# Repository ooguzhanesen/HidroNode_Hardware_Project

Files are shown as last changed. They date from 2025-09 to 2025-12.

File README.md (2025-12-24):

# STM32WL HidroNode – Donanım Tasarım Dokümantasyonu

> **Hazırlayan:** Oğuzhan ESEN  
> **Proje Adı:** HidroNode Board 
> **Tarih:** 24 Eylül 2025  
> **Versiyon:** v1.0
---

## İçindekiler

1. [Giriş](#1-giriş)  
2. [Tasarımın Amacı ve Kapsamı](#2-tasarımın-amacı-ve-kapsamı)  
3. [Sistem Blok Diyagramı](#3-sistem-blok-diyagramı)  
4. [Tasarım Özeti](#4-tasarım-özeti)  
5. [Şematik ve PCB](#5-şematik-ve-pcb)  
6. [Test Notları](#6-test-notları)  
7. [Geliştirme ve İyileştirme Önerileri](#7-geliştirme-ve-iyileştirme-önerileri)
---

## 1. Giriş

Bu doküman, LoraSOM Kartının taşıyıcısını  olan HidroNode kartını açıklamayı amaçlamaktadır. 
Tasarım, aşağıdaki isterleri karşılamak üzere gerçekleştirilmiştir:

- LoraSOM kartı ile pin uyumu sağlanması.
- Sensörlerle Dijital haberleşme yapabilmesi için **(TPEC)** RS485 engtegresinin bulunması.
- Sensörlerle Analog haberleşme yapabilmesi için **(Radar)** 4-20mA okuma girişinin bulunması.
- Dijital çıkış ile çalışan sensörlerden veri okuyabilmesi için **(Yağmur Sensörü)** dijital girişin bulunması.
- Arazi koşullarında Akü ve benzeri bataryalarla çalışabilmesi için 7-28 V girişi regüle edebilesi.
- Sensör çıkışlarının votajının sabitlenmesi(15v).
- Tassaruf amacıyla sensorleri kullanılmadığında kapatması.
- Dijital giriş çıkışların izole edilmesi.

---

## 2. Tasarımın Amacı ve Kapsamı
Proje kapsamında, LoraSOM kartının güvenli şekilde sensörlerden gelen verileri okuması ve çevresel şartlarda çalışması amaçlanmaktadır.

Taşıyıcı kart, aşağıdaki teknik özellikleri ile ölçüm istasyonlarındaki ihtiyaçları karşılamaktadır:

- **RS485 Haberleşme**  
  MAX3075EESA entegresi ile TPEC gibi endüstriyel sensörler ile haberleşme sağlanır.

- **Analog Sensör Girişi (4–20 mA)**  
  150 Ω shunt direnç, 2 adet opamp ve zener koruma ile akım döngülü sensörlerden gelen analog değer 16 bit çözünürlüğe sahip ADS1115IDGS entegresine bağlanır. Bu entegre de I2C ile LoraSOM'a Bağlıdır.

- **Panel Gerilim Okuma**  
  150 kΩ ve 20 kΩ direnç bölücü ile güneş panelinden voltaj ölçümü yapılabilir.

- **İzole Dijital Giriş**  
  Optokuplör korumalı 2 adet dijital giriş ile dijital çıkışlı ( yağmur sensörü) sensörlerden veri okunabilir.

- **İzole Dijital Çıkışlar**  
  4 adet dijital çıkış LTV-847S entegresi sayesinde izole şekilde röle veya kontrol elemanları sürülebilir.

- **Geniş Giriş Gerilim Aralığı**  
  TPS54302 ve TPS62291DRVR entegreleri ile 7–28 V DC giriş, 5 V ve 3.3 V seviyelerine güvenli şekilde regüle edilir.

- **Sensör Güç çıkışlarının Sabitlenmesi ve Kontrolü (15V)**  
  MT3608 entegresi ile 5v 15v yükselterek sensörlerin akü voltajına bağımlı kalması engellenmiştir. Ayrıca MT3608 entegresin enable pini ile bu çıkışlar anahtarlanmaktadır. 

---

## 3. Sistem Blok Diyagramı

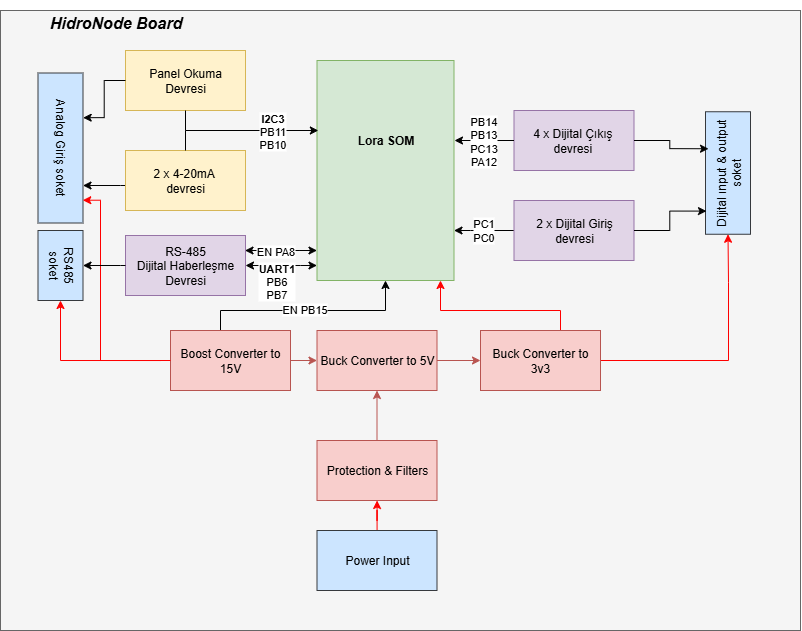
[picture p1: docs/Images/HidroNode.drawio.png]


## 4. Tasarım Özeti

Tasarım 4 katlı olacak şekikde KiCAD üzerinden tasarlanmıştır.

## 5. Şematik ve PCB
[Şematik için tıklayın](docs/HidroNode_Project.pdf)

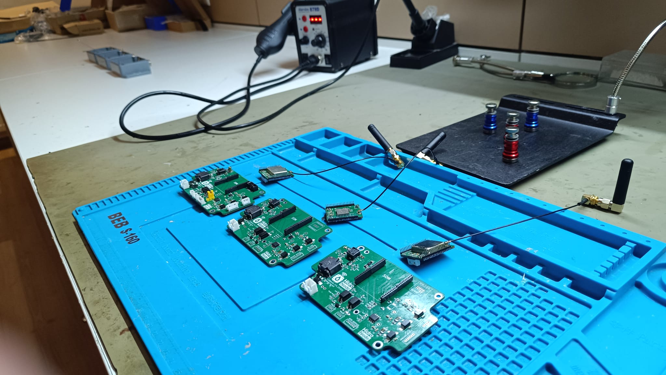
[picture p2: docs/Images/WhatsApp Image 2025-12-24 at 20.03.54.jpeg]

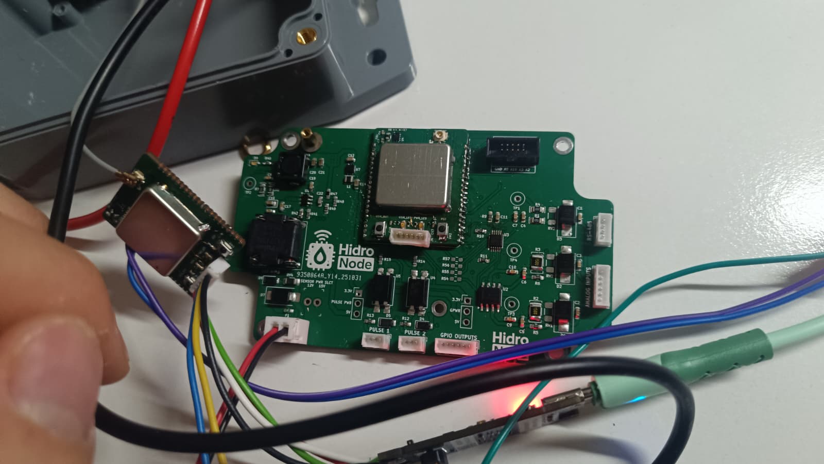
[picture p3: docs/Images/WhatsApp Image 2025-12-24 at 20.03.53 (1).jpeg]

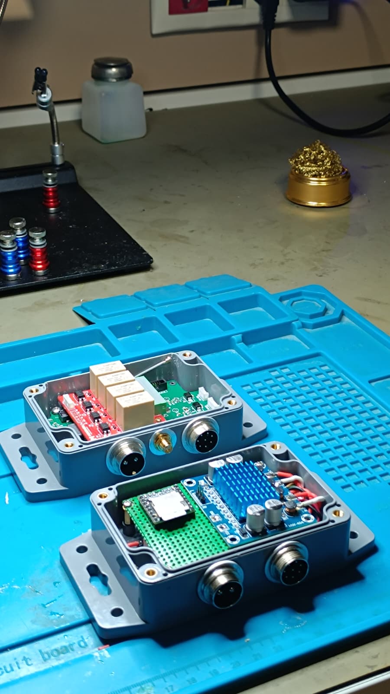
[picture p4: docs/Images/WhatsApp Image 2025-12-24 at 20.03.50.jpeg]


---
## 6. Test Notları
* 5v regülatör devresinde 75pf olmadıgı için en yakın deger olan 68pf kullanıldı.

---
## 7. Geliştirme ve İyileştirme Önerileri

* indüktör footprinti güncellenebilir.
* tvs diyot kıfı küçültülebilir.
* Genişleme portunun slikscreeni düzeltilecek. 
* Kart soket tipi degistirilebilir 

--- 

## Eksikler
* Anten kablosu alınacak.
* kart montajı için vida alınacak
* genişleme portu karsılık soketi alınacak
* hoparlor modulunun voltajı 3.3 volta dusurulecek.
* sbrr alınması gerek. 1 adet kaldı.  
* 150 ohm sont bitti.

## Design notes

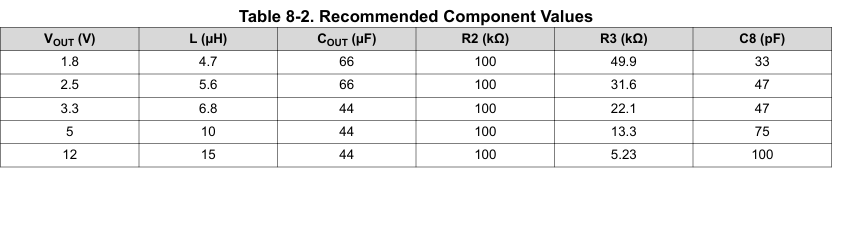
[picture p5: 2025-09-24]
docs/Images/Screenshot_4.png

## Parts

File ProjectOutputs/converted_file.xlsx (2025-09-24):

Reference | Value | Footprint | Qty | OZDISAN
C1,C2,C3,C5,C6,C7,C8,C9,C10 | 10nF | Capacitor_SMD:C_0603_1608Metric_Pad1.08x0.95mm_HandSolder | 9 | CL10B103KB8NNNC
C4,C11,C13,C15,C17,C19,C24 | 100nF | Capacitor_SMD:C_0603_1608Metric_Pad1.08x0.95mm_HandSolder | 7 | CC0603KRX7R9BB104
C12,C14,C16 | 10uF | Capacitor_SMD:C_0603_1608Metric,Capacitor_SMD:C_0603_1608Metric_Pad1.08x0.95mm_HandSolder,LED_SMD:LED_0805_2012Metric_Pad1.15x1.40mm_HandSolder | 3 | CL10A106KQ8NNNC,GRM21BC8YA106KE11L
C18,C20,C21,C23 | 22uF | Capacitor_SMD:C_0603_1608Metric_Pad1.08x0.95mm_HandSolder,Capacitor_SMD:C_1206_3216Metric_Pad1.33x1.80mm_HandSolder | 4 | CL31A226KAHNNNE,GRM188C61E226ME01J
C22 | 75pF | Capacitor_SMD:C_0603_1608Metric_Pad1.08x0.95mm_HandSolder | 1 | CL10C680JB8NNNC
D1,D2,D3,D7 | SMBJ28A-HT | Diode_SMD:D_SMB_Handsoldering | 4 | SMBJ28A-HT
D4,D5,D6,D8 | SBR3U40P1-7 | Diode_SMD:D_PowerDI-123 | 4 | SBR3U40P1-7
D9 | LED | LED_SMD:LED_0603_1608Metric_Pad1.05x0.95mm_HandSolder | 1 | HSMQ-C191
D10 | SS34 | digikey-footprints:DO-214AB | 1 | SS34-DO214AB-HT
F1 | 2A | Fuse:Fuse_0603_1608Metric_Pad1.05x0.95mm_HandSolder | 1 | 3412.0119.22
J1,J3,J4,J7,J8,J9,U1 | ~ | Connector_Hirose:Hirose_DF13-06P-1.25DSA_1x06_P1.25mm_Vertical,Connector_PinHeader_2.54mm:PinHeader_1x03_P2.54mm_Vertical,Connector_PinHeader_2.54mm:PinHeader_2x01_P2.54mm_Vertical,mergened_footprints:BoxHeader2x5_1.27,mergened_footprints:stm32wl_lora_som | 7 | 4573-06MTSB
J2 | B4B-PH-K-S_LF__SN_ | Connector_Hirose:Hirose_DF13-04P-1.25DSA_1x04_P1.25mm_Vertical | 1
J5,J6 | B3B-PH-K-S_LF__SN_ | Connector_Molex:Molex_PicoBlade_53047-0310_1x03_P1.25mm_Vertical | 2 | https://www.hepsiburada.com/labshop41-jst-1-25mm-3pin-20cm-kablolu-konnektor-beyaz-takim-x-1-adet-rf014-p-HBCV00006C588M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
J10 | 22-23-2021 | digikey-footprints:PinHeader_1x2_P2.54mm_Drill1.02mm | 1
L1 | 2.2uH | Inductor_SMD:L_Murata_DFE201610P | 1 | LQM2MPN2R2NG0L
L2 | PA2748NL | footprints:pa2748 | 1 | PA2748NL
L3 | 22uH | Inductor_SMD:L_12x12mm_H6mm | 1 | SRI1204-220M
L4 | 10uH | footprints:INDC6060X300 | 1 | SRI0704-100M
Q1,Q2,Q5,Q6,Q9 | BC817-40,215 | Package_TO_SOT_SMD:SOT-23 | 5 | BC817-40,215
Q3,Q4,Q7,Q8 | BC857B,215 | Package_TO_SOT_SMD:SOT-23-3 | 4 | BC857B,215
Q10 | BSN20 | Package_TO_SOT_SMD:SOT-23 | 1 | BSN20BK
R1,R7 | 150k | Resistor_SMD:R_0805_2012Metric_Pad1.20x1.40mm_HandSolder | 2 | TC0550B1503T5G
R2,R3,R26,R27,R38,R39 | 150 | Resistor_SMD:R_1206_3216Metric_Pad1.30x1.75mm_HandSolder,Resistor_SMD:R_1210_3225Metric | 6 | ERJ8GEYJ151V,RN73H2ETTD1500B25
R4,R8 | 20k | Resistor_SMD:R_0805_2012Metric_Pad1.20x1.40mm_HandSolder | 2 | TC0525B2002T5G
R5,R6,R17,R32,R33 | 1k | Resistor_SMD:R_0603_1608Metric_Pad0.98x0.95mm_HandSolder | 5 | CRT03F7E1001
R9,R10,R11,R14,R15,R22,R23,R24,R25,R34,R35,R36,R37,R44,R51,R52,R53 | 10k | Resistor_SMD:R_0603_1608Metric_Pad0.98x0.95mm_HandSolder | 17 | 0603SAJ0103TDE
R12,R13 | 1.1k | Resistor_SMD:R_0603_1608Metric_Pad0.98x0.95mm_HandSolder | 2 | 0603SAF1101T5E
R16,R20,R21,R28,R29,R43 | 1K | Resistor_SMD:R_0603_1608Metric_Pad0.98x0.95mm_HandSolder | 6 | CRT03F7E1001
R18,R19,R30,R31 | 680 | Resistor_SMD:R_0603_1608Metric_Pad0.98x0.95mm_HandSolder | 4 | 0603SAF6800T5E
R40,R50 | 210 | Resistor_SMD:R_0603_1608Metric_Pad0.98x0.95mm_HandSolder | 2 | 0603SAF2100T5E,RC0805FR-070RL
R41 | 511k | Resistor_SMD:R_0603_1608Metric_Pad0.98x0.95mm_HandSolder | 1 | 0603SAF1053T5E
R42 | 105k | Resistor_SMD:R_0603_1608Metric_Pad0.98x0.95mm_HandSolder | 1 | 0603SAF1053T5E
R45 | 75k | Resistor_SMD:R_0603_1608Metric_Pad0.98x0.95mm_HandSolder | 1 | 0603SAF7502T5E
R46 | 3.3k | Resistor_SMD:R_0603_1608Metric_Pad0.98x0.95mm_HandSolder | 1 | 0603SAJ0332T5E
R47 | 49.9 | Resistor_SMD:R_0603_1608Metric_Pad0.98x0.95mm_HandSolder | 1 | 0603SAF499JT5E
R48 | 100K | Resistor_SMD:R_0603_1608Metric_Pad0.98x0.95mm_HandSolder | 1 | RC0805JR-07100KL
R49 | 13.3K | Resistor_SMD:R_0603_1608Metric_Pad0.98x0.95mm_HandSolder | 1 | 0603SAF1332T5E
RV1,RV2,RV3,RV4 | TVM3B390K651TY | Resistor_SMD:R_1206_3216Metric_Pad1.30x1.75mm_HandSolder | 4 | TVM3B390K651TY
TP1,TP2,TP3,TP4 | TestPoint | TestPoint:TestPoint_Loop_D2.60mm_Drill0.9mm_Beaded | 4
U2 | OPA2197xD | Package_SO:SOIC-8_3.9x4.9mm_P1.27mm | 1 | OPA2197IDR
U3 | ADS1115IDGS | Package_SO:TSSOP-10_3x3mm_P0.5mm | 1 | ADS1115IDGST
U4,U5 | UPC817BG-C04-R | mergened_footprints:EL8171-S1-TU_EVE | 2 | UPC817BG-C04-R
U6 | LTV-847S | Package_DIP:SMDIP-16_W9.53mm | 1 | LTV-847S
U7 | TPS62291DRVR | footprints:WSON6 (2x2) | 1 | TPS62291DRVR
U8 | TPS54302 | Package_TO_SOT_SMD:SOT-23-6 | 1 | TPS54302DDCR
U9 | MT3608 | Package_TO_SOT_SMD:SOT-23-6 | 1 | https://www.direnc.net/mt3608-2a-max-dc-dc-step-up-power-module-arduino?language=tr&h=60f3a44c
U10 | Max3075EESA | Package_SO:SOIC-8_3.9x4.9mm_P1.27mm | 1

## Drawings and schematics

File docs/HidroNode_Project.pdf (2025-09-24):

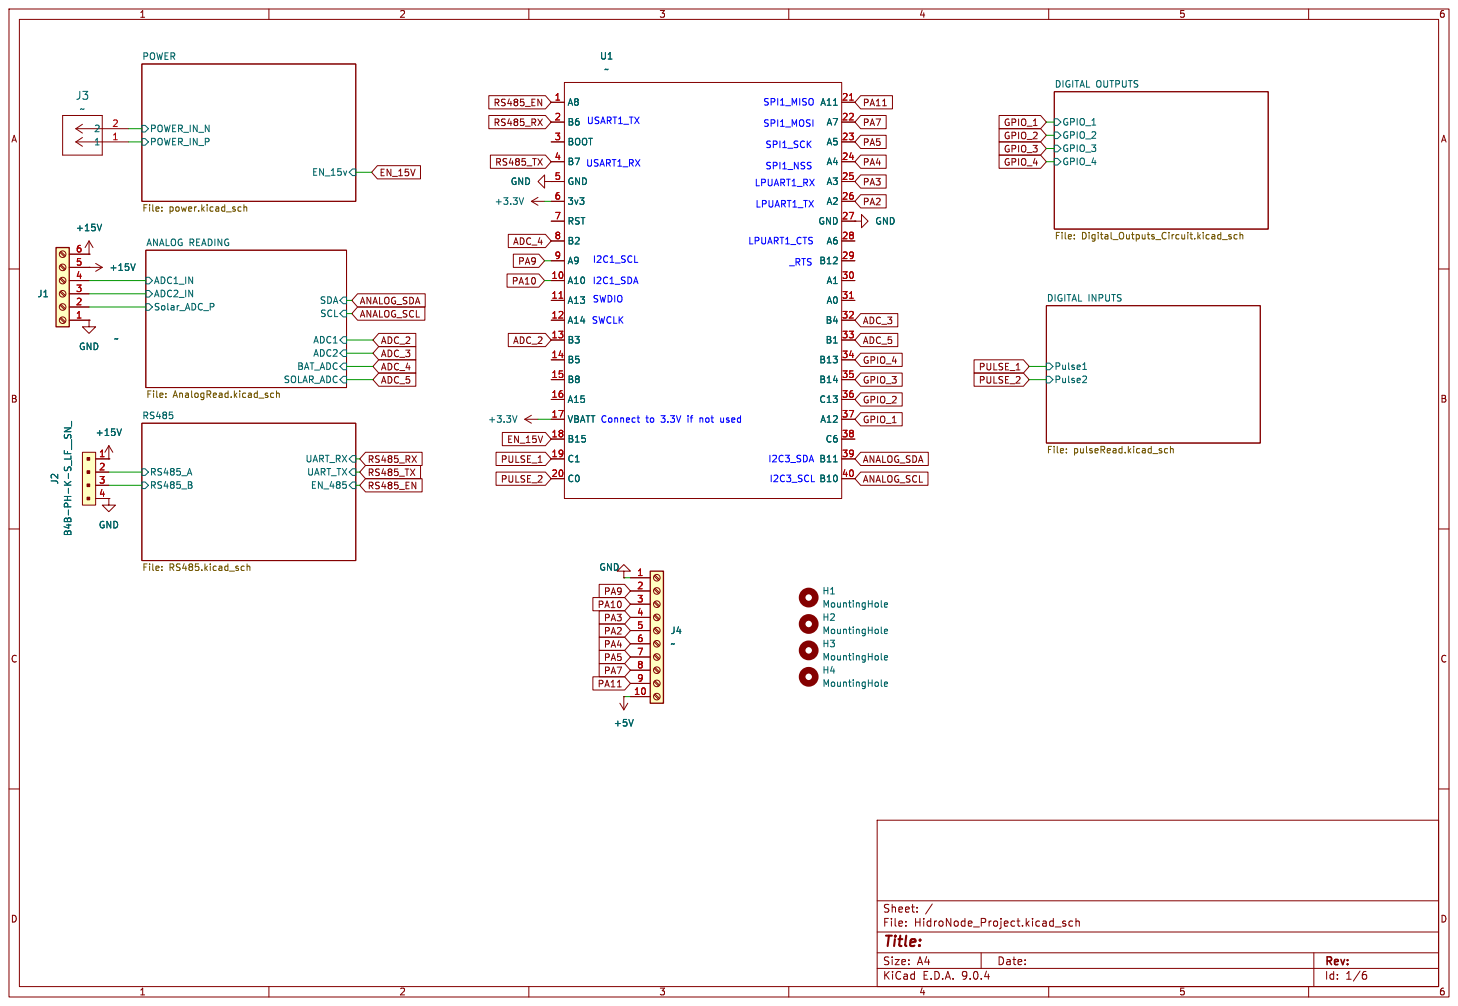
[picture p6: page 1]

SWCLK Connect to 3.3V if not used

Id: 1/6 Title: File: HidroNode_Project.kicad_sch Sheet: /

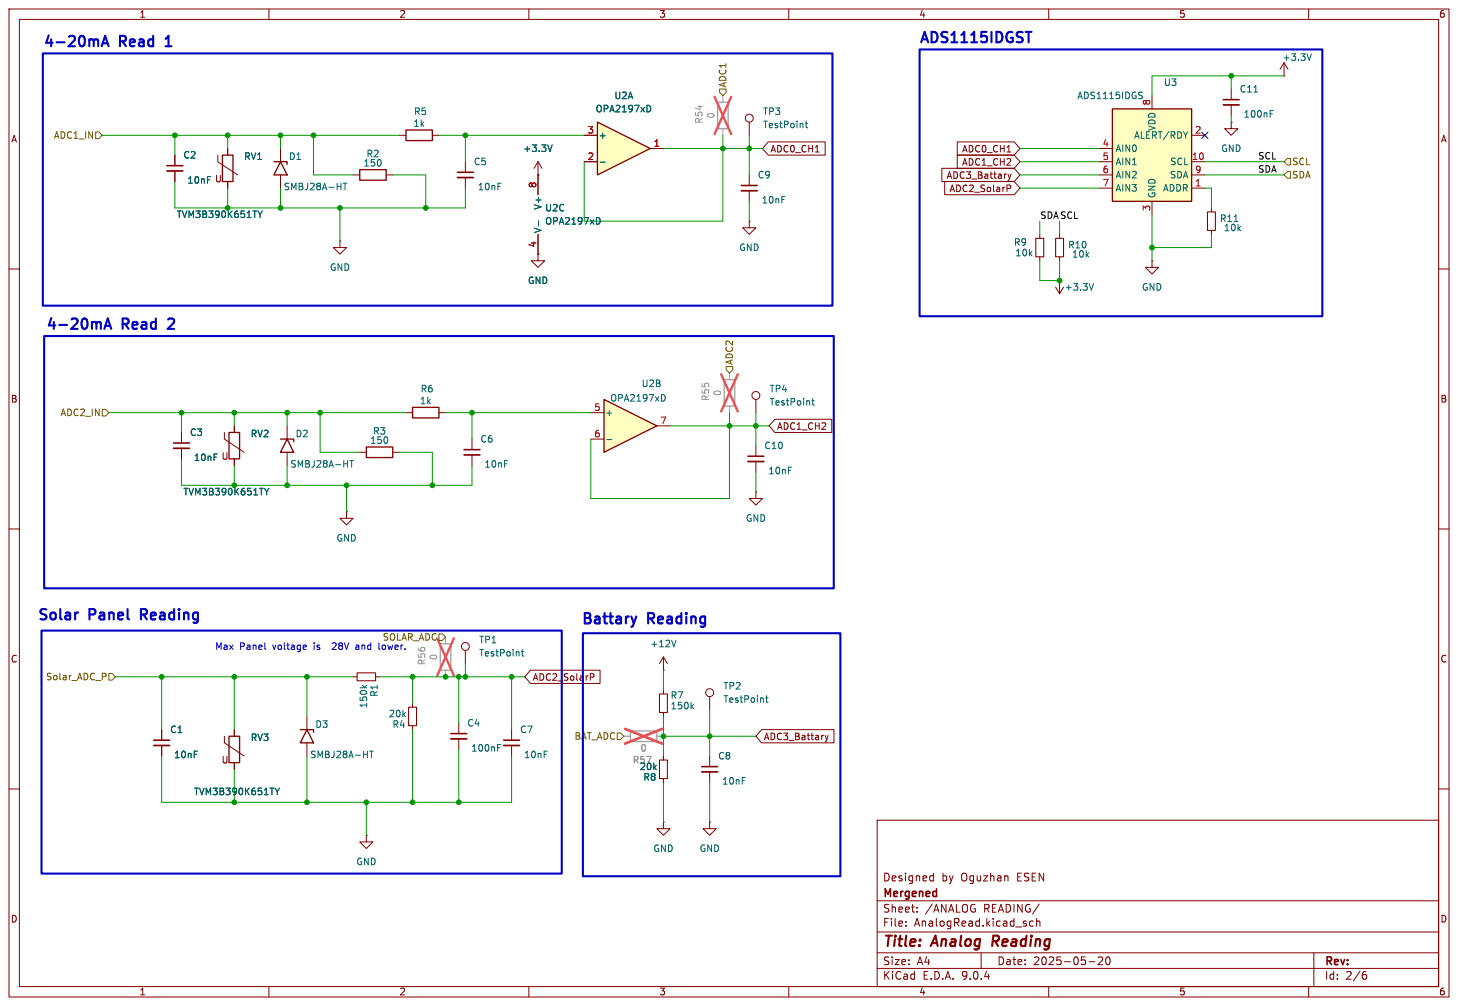
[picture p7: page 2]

3 ALERT/RDY 2 SCL 10 SDA 9 ADDR 1 U3 ADS1115IDGS GND

Id: 2/6 Title: Analog Reading

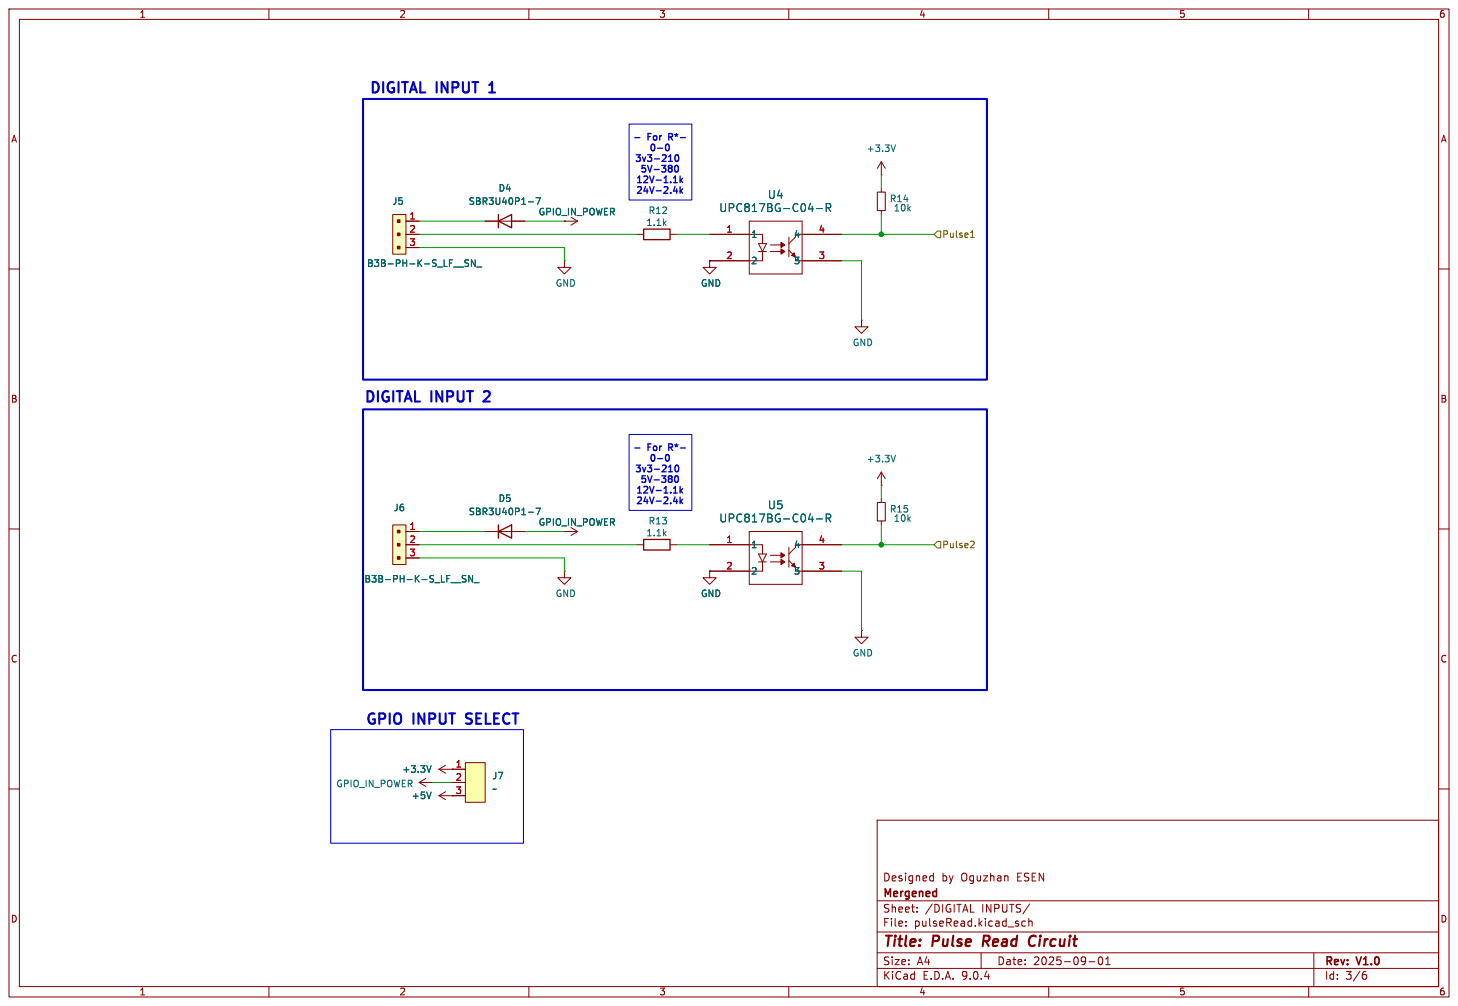
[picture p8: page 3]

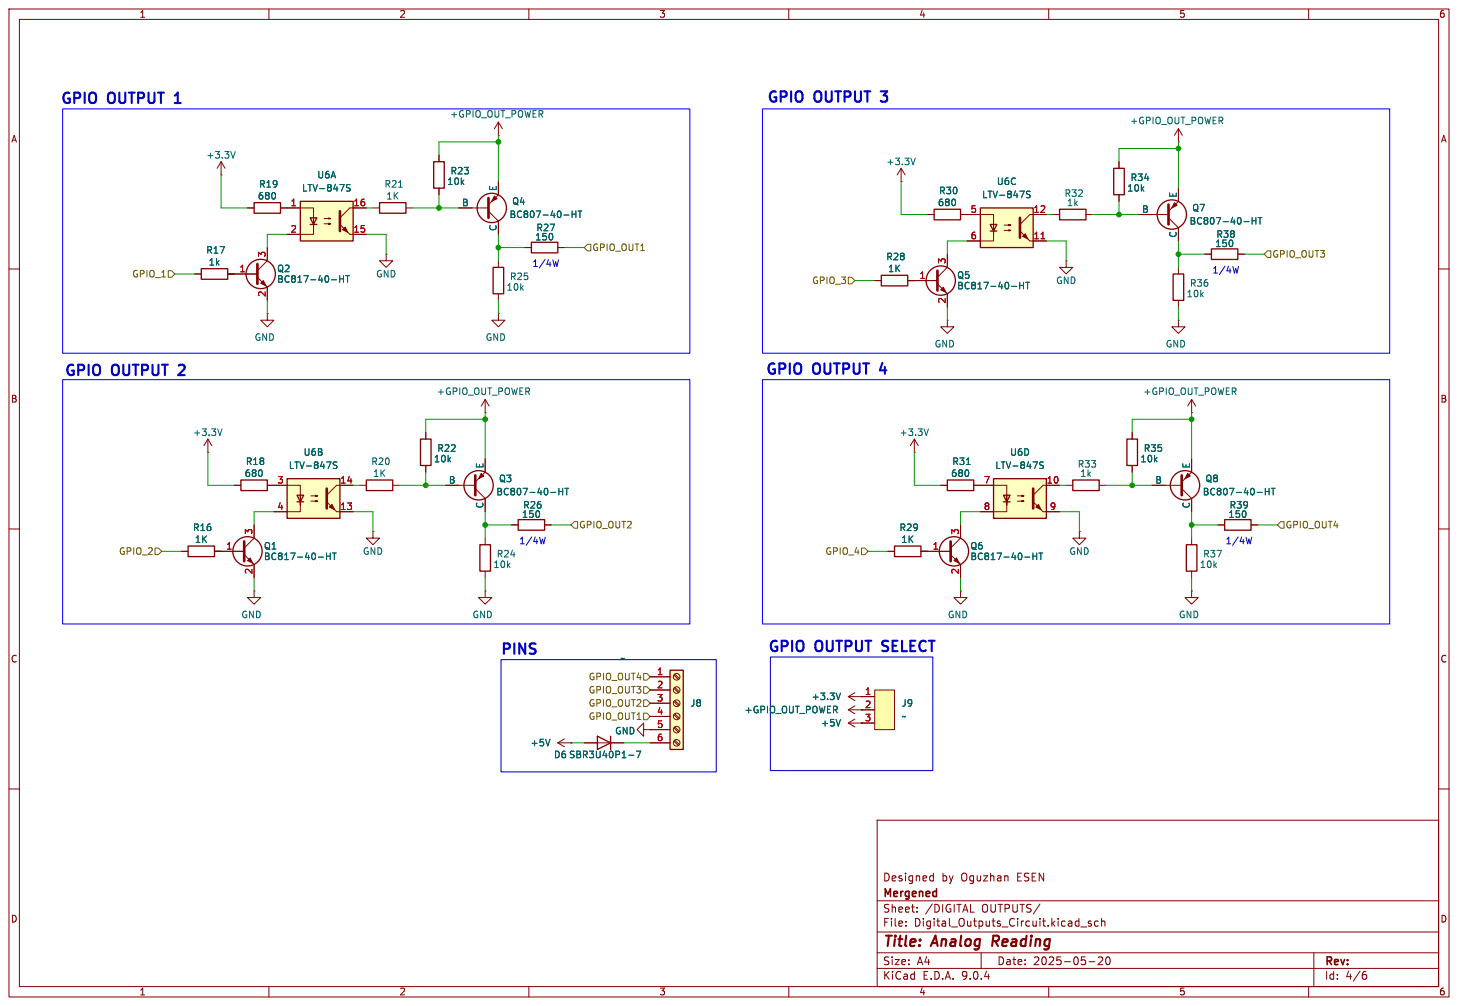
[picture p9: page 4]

Id: 4/6 Title: Analog Reading

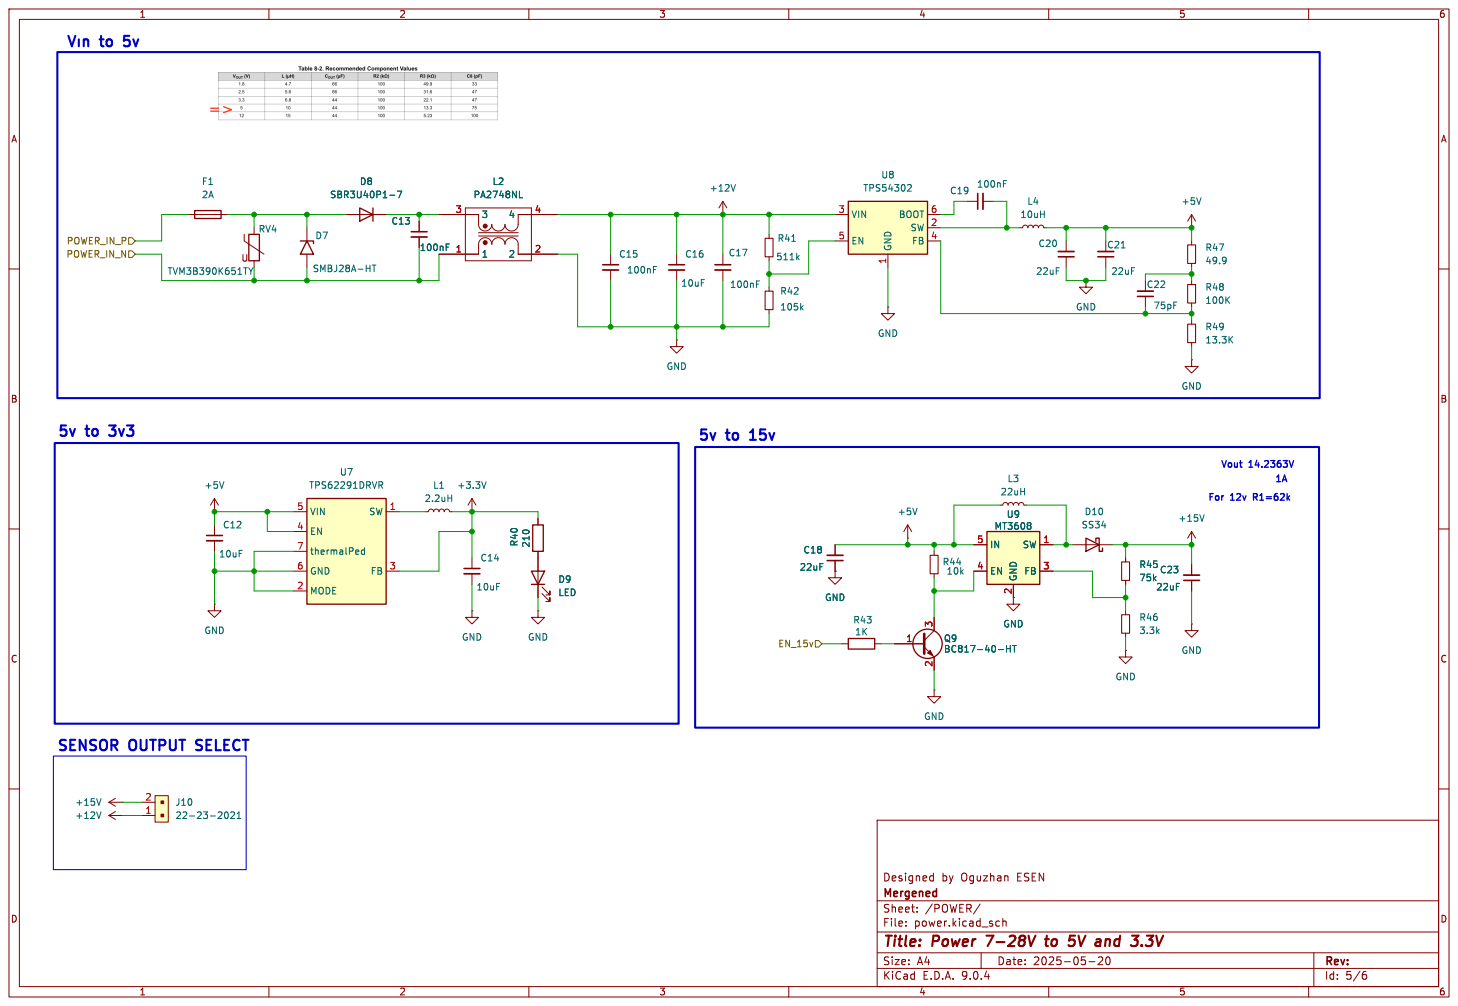
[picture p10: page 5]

File: power.kicad_sch Sheet: /POWER/ Mergened

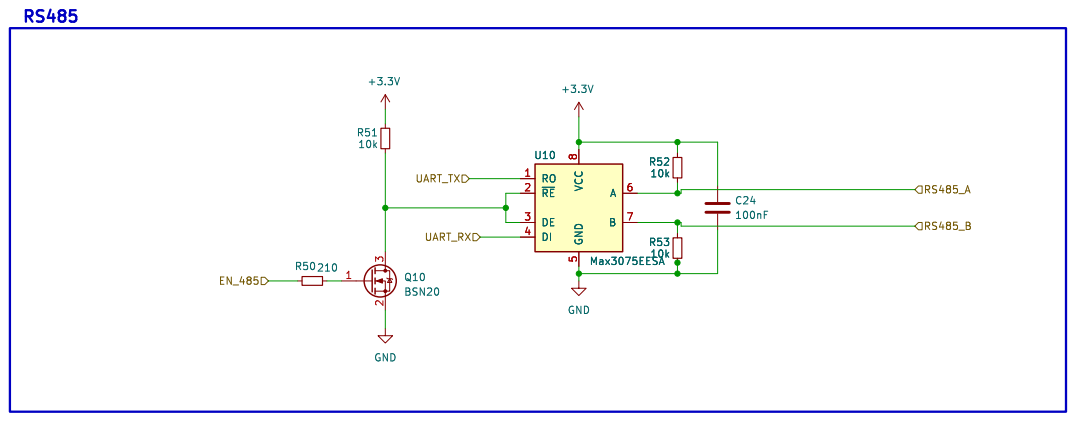
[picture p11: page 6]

Id: 6/6 Title: File: RS485.kicad_sch Sheet: /RS485/

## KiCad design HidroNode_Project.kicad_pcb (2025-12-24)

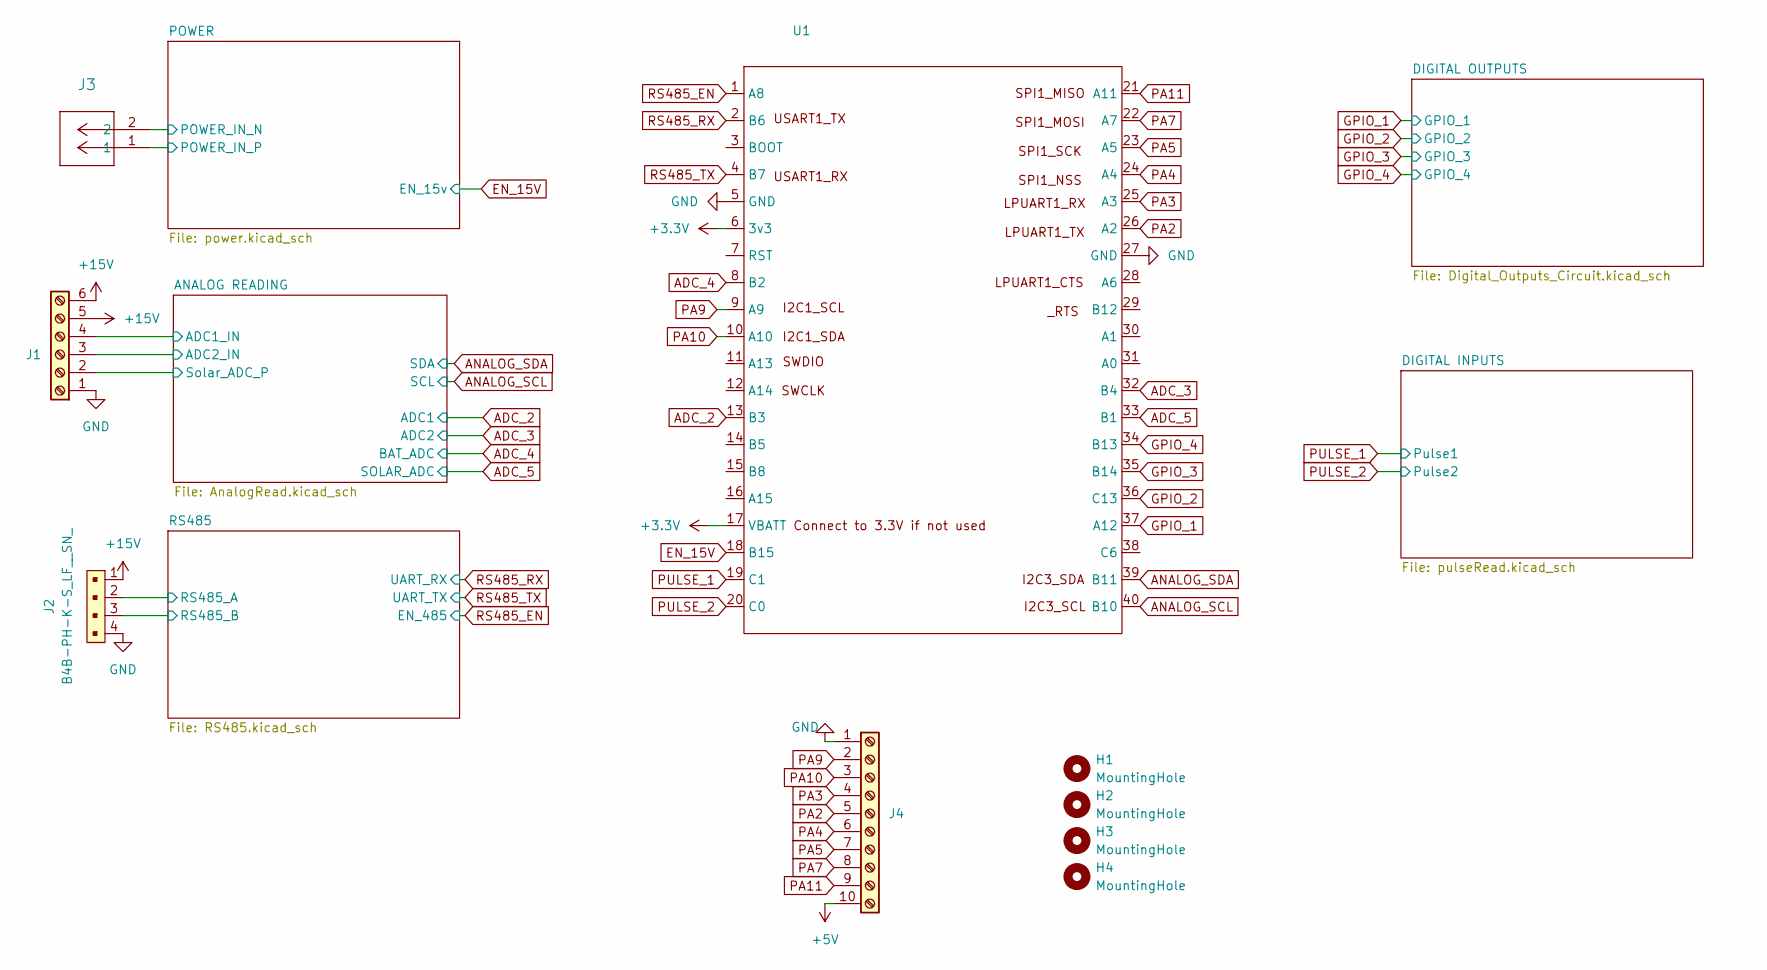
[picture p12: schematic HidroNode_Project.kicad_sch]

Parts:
H1, H2: MountingHole; MountingHole_3.2mm_M3_ISO14580_Pad
H3, H4: MountingHole; MountingHole_2.7mm_M2.5_DIN965_Pad
J1: Hirose_DF13-06P-1.25DSA_1x06_P1.25mm_Vertical
J2: B4B-PH-K-S_LF__SN_; Hirose_DF13-04P-1.25DSA_1x04_P1.25mm_Vertical; MPN B4B-PH-K-S(LF)(SN); Digi-Key_PN 455-1706-ND
J3: PinHeader_2x01_P2.54mm_Vertical
J4: BoxHeader2x5_1.27
U1: stm32wl_lora_som

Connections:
+3.3V: U1.6 (3v3), U1.17 (VBATT); also elsewhere on the board
+5V: J4.10; also elsewhere on the board
+15V: J1.5, J1.6, J2.1; also elsewhere on the board
/ANALOG READING/ADC1_IN: J1.4; also elsewhere on the board
/ANALOG READING/ADC2_IN: J1.3; also elsewhere on the board
/ANALOG READING/Solar_ADC_P: J1.2; also elsewhere on the board
/POWER/POWER_IN_N: J3.2; also elsewhere on the board
/POWER/POWER_IN_P: J3.1; also elsewhere on the board
/RS485/RS485_A: J2.2; also elsewhere on the board
/RS485/RS485_B: J2.3; also elsewhere on the board
ADC_2: U1.13 (B3); also elsewhere on the board
ADC_3: U1.32 (B4); also elsewhere on the board
ADC_4: U1.8 (B2); also elsewhere on the board
ADC_5: U1.33 (B1); also elsewhere on the board
ANALOG_SCL: U1.40 (B10); also elsewhere on the board
ANALOG_SDA: U1.39 (B11); also elsewhere on the board
EN_15V: U1.18 (B15); also elsewhere on the board
GND: J1.1, J2.4, J4.1, U1.5 (GND), U1.27 (GND); also elsewhere on the board
GPIO_1: U1.37 (A12); also elsewhere on the board
GPIO_2: U1.36 (C13); also elsewhere on the board
GPIO_3: U1.35 (B14); also elsewhere on the board
GPIO_4: U1.34 (B13); also elsewhere on the board
PA2: J4.5, U1.26 (A2)
PA3: J4.4, U1.25 (A3)
PA4: J4.6, U1.24 (A4)
PA5: J4.7, U1.23 (A5)
PA7: J4.8, U1.22 (A7)
PA9: J4.2, U1.9 (A9)
PA10: J4.3, U1.10 (A10)
PA11: J4.9, U1.21 (A11)
PULSE_1: U1.19 (C1); also elsewhere on the board
PULSE_2: U1.20 (C0); also elsewhere on the board
RS485_EN: U1.1 (A8); also elsewhere on the board
RS485_RX: U1.2 (B6); also elsewhere on the board
RS485_TX: U1.4 (B7); also elsewhere on the board

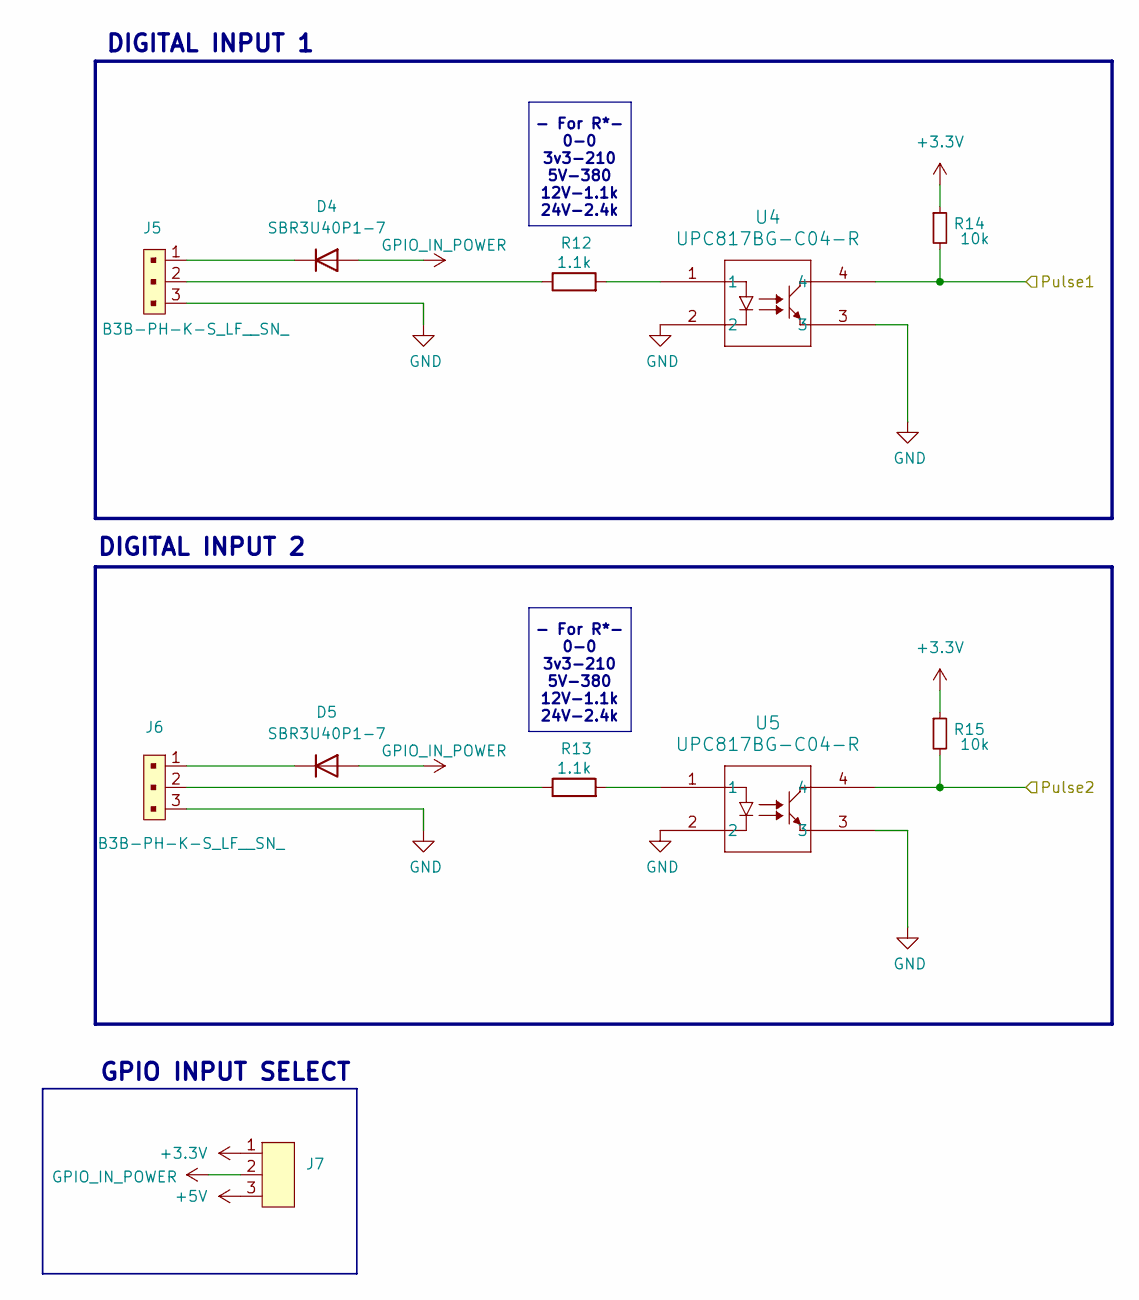
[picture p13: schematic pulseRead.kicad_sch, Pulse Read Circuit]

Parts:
D4, D5: SBR3U40P1-7; D_PowerDI-123
J5, J6: B3B-PH-K-S_LF__SN_; Molex_PicoBlade_53047-0310_1x03_P1.25mm_Vertical; MPN B3B-PH-K-S(LF)(SN); DigiKey 277-1207-ND
J7: PinHeader_1x03_P2.54mm_Vertical
R12, R13: 1.1k; R_0603_1608Metric_Pad0.98x0.95mm_HandSolder
R14, R15: 10k; R_0603_1608Metric_Pad0.98x0.95mm_HandSolder
U4, U5: UPC817BG-C04-R; EL8171-S1-TU_EVE; DigiKey 080-1603-2-ND

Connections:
+3.3V: J7.1, R14.1, R15.1; also elsewhere on the board
+5V: J7.3; also elsewhere on the board
GND: J5.3, J6.3, U4.2, U4.3, U5.2, U5.3; also elsewhere on the board
GPIO_IN_POWER: D4.2 (A), D5.2 (A), J7.2
unnamed: D4.1 (K), J5.1
unnamed: D5.1 (K), J6.1
unnamed: J5.2, R12.1
unnamed: J6.2, R13.1
unnamed: R12.2, U4.1
unnamed: R13.2, U5.1
PULSE_1: R14.2, U4.4; also elsewhere on the board
PULSE_2: R15.2, U5.4; also elsewhere on the board

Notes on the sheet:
GPIO INPUT SELECT
DIGITAL INPUT 1
DIGITAL INPUT 2
- For R*- 0-0 3v3-210 5V-380 12V-1.1k 24V-2.4k

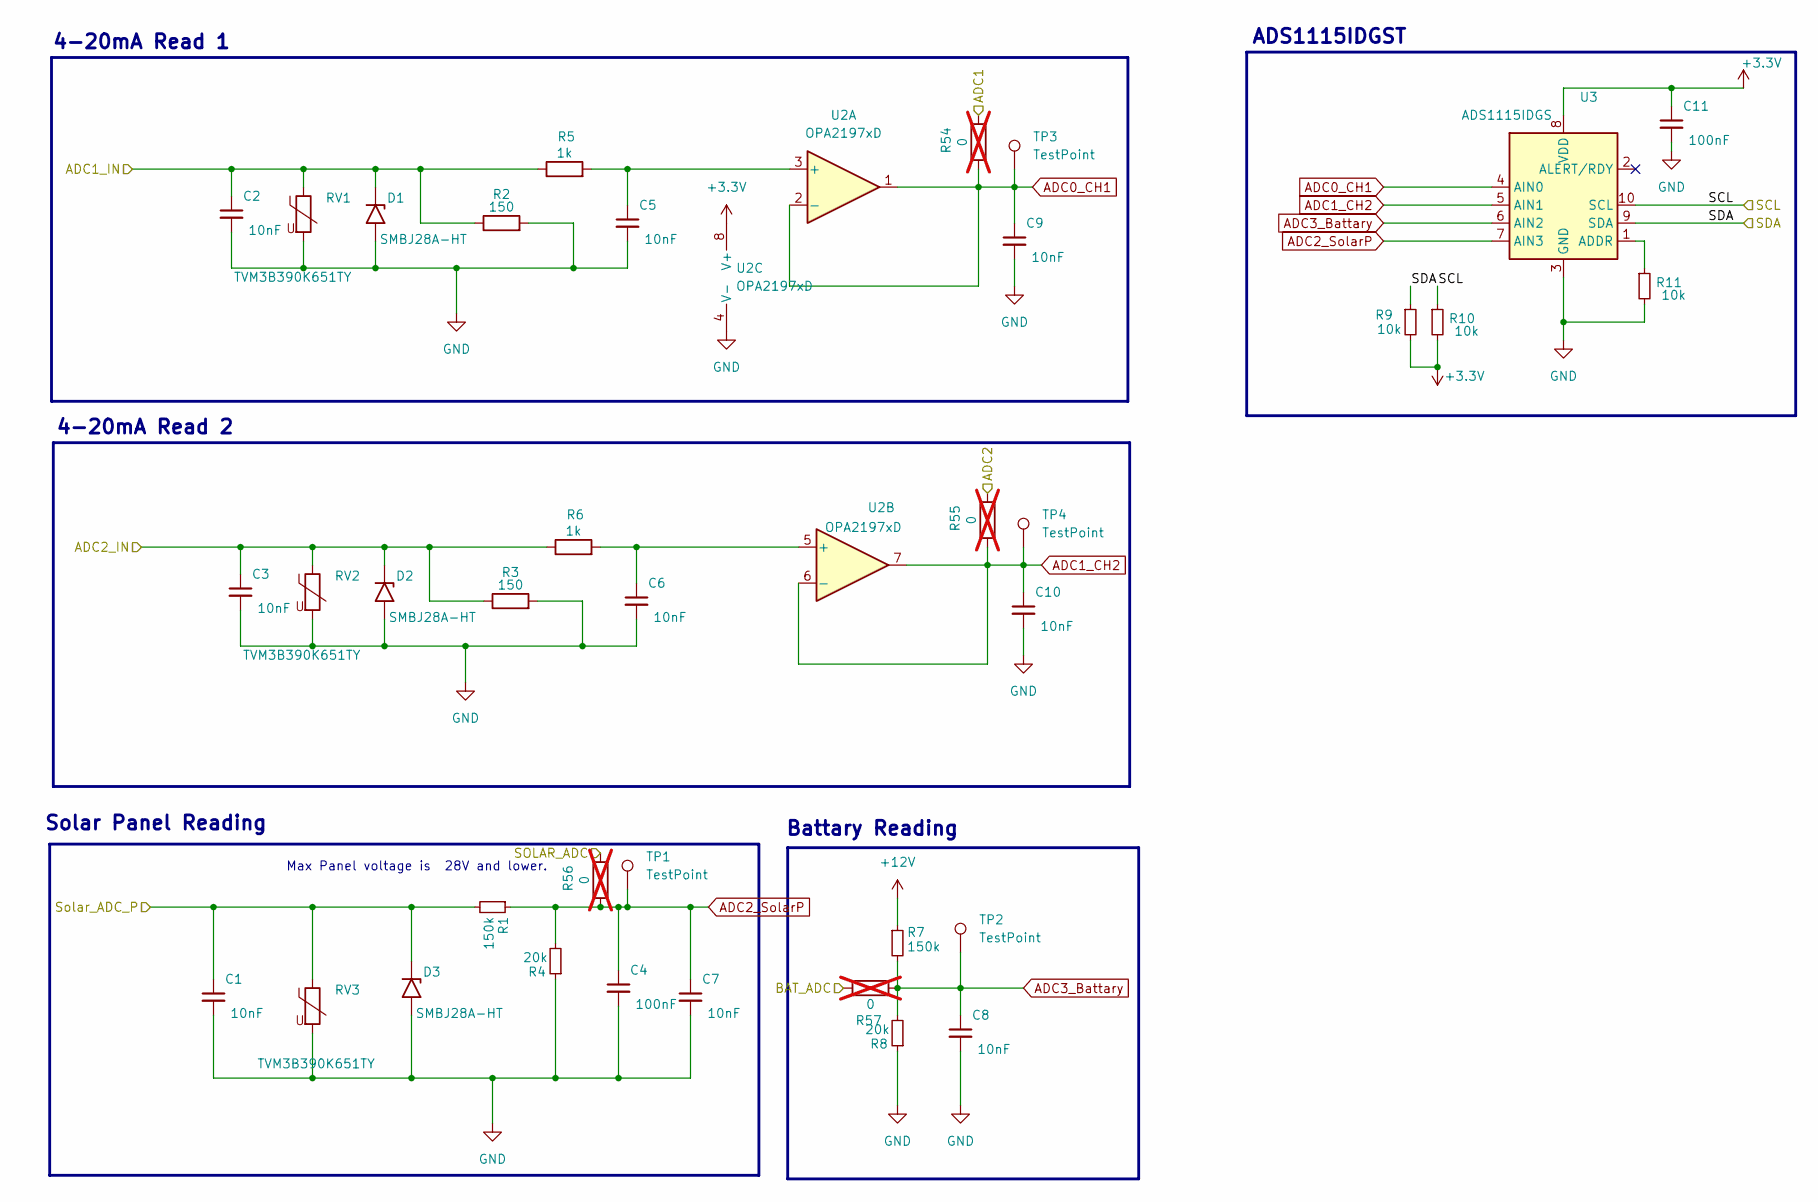
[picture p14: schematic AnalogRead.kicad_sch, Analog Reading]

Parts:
C1, C2, C3, C5, C6, C7, C8, C9, C10: 10nF; C_0603_1608Metric_Pad1.08x0.95mm_HandSolder
C4, C11: 100nF; C_0603_1608Metric_Pad1.08x0.95mm_HandSolder
D1, D2, D3: SMBJ28A-HT; D_SMB_Handsoldering
R1, R7: 150k; R_0805_2012Metric_Pad1.20x1.40mm_HandSolder
R2, R3: 150; R_1210_3225Metric
R4, R8: 20k; R_0805_2012Metric_Pad1.20x1.40mm_HandSolder
R5, R6: 1k; R_0603_1608Metric_Pad0.98x0.95mm_HandSolder
R9, R10, R11: 10k; R_0603_1608Metric_Pad0.98x0.95mm_HandSolder
R54, R55, R56, R57: 0; R_0603_1608Metric_Pad0.98x0.95mm_HandSolder; not fitted
RV1, RV2, RV3: TVM3B390K651TY; R_1206_3216Metric_Pad1.30x1.75mm_HandSolder
TP1, TP2, TP3, TP4: TestPoint; TestPoint_Loop_D2.60mm_Drill0.9mm_Beaded
U2: OPA2197xD; SOIC-8_3.9x4.9mm_P1.27mm
U3: ADS1115IDGS; TSSOP-10_3x3mm_P0.5mm

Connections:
+3.3V: C11.1, R9.2, R10.2, U2.8 (V+), U3.8 (VDD); also elsewhere on the board
+12V: R7.1; also elsewhere on the board
/ANALOG READING/ADC1_IN: C2.1, D1.1 (A1), R2.1, R5.1, RV1.1; also elsewhere on the board
/ANALOG READING/ADC2_IN: C3.1, D2.1 (A1), R3.1, R6.1, RV2.1; also elsewhere on the board
/ANALOG READING/Solar_ADC_P: C1.1, D3.1 (A1), R1.2, RV3.1; also elsewhere on the board
ADC0_CH1: C9.1, R54.1, TP3.1, U2.1, U2.2 (-), U3.4 (AIN0)
ADC1_CH2: C10.1, R55.1, TP4.1, U2.6 (-), U2.7, U3.5 (AIN1)
ADC2_SolarP: C4.1, C7.1, R1.1, R4.2, R56.1, TP1.1, U3.7 (AIN3)
ADC3_Battary: C8.1, R7.2, R8.2, R57.1, TP2.1, U3.6 (AIN2)
ADC_2: R54.2; also elsewhere on the board
ADC_3: R55.2; also elsewhere on the board
ADC_4: R57.2; also elsewhere on the board
ADC_5: R56.2; also elsewhere on the board
ANALOG_SCL: R10.1, U3.10 (SCL); also elsewhere on the board
ANALOG_SDA: R9.1, U3.9 (SDA); also elsewhere on the board
GND: C1.2, C2.2, C3.2, C4.2, C5.2, C6.2, C7.2, C8.2, C9.2, C10.2, C11.2, D1.2 (A2), D2.2 (A2), D3.2 (A2), R2.2, R3.2, R4.1, R8.1, R11.2, RV1.2, RV2.2, RV3.2, U2.4 (V-), U3.3 (GND); also elsewhere on the board
unnamed: C5.1, R5.2, U2.3 (+)
unnamed: C6.1, R6.2, U2.5 (+)
unnamed: R11.1, U3.1 (ADDR)

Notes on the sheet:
Battary Reading
4-20mA Read 2
Solar Panel Reading
4-20mA Read 1
ADS1115IDGST
Max Panel voltage is 28V and lower.

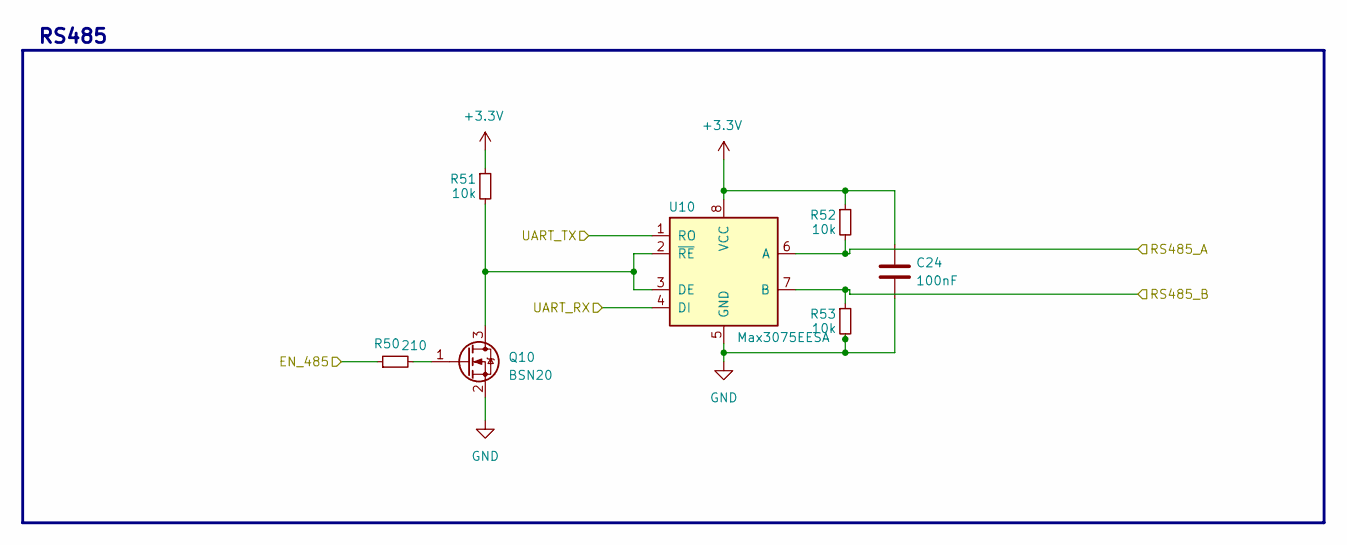
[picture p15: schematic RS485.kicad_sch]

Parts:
C24: 100nF; C_0603_1608Metric_Pad1.08x0.95mm_HandSolder; DIGIKEY 3372-0402B104K500HITR-ND
Q10: BSN20; SOT-23; DIGIKEY BSN20-7DITR-ND
R50: 210; R_0603_1608Metric_Pad0.98x0.95mm_HandSolder; DIGIKEY 541-0.0GTR-ND
R51, R52, R53: 10k; R_0603_1608Metric_Pad0.98x0.95mm_HandSolder
U10: Max3075EESA; SOIC-8_3.9x4.9mm_P1.27mm; DIGIKEY MAX3075EESA+-ND

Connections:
+3.3V: C24.1, R51.1, R52.1, U10.8 (VCC); also elsewhere on the board
/RS485/RS485_A: R52.2, U10.6 (A); also elsewhere on the board
/RS485/RS485_B: R53.1, U10.7 (B); also elsewhere on the board
GND: C24.2, Q10.2 (S), R53.2, U10.5 (GND); also elsewhere on the board
unnamed: Q10.3 (D), R51.2, U10.2 (~RE), U10.3 (DE)
unnamed: Q10.1 (G), R50.2
RS485_EN: R50.1; also elsewhere on the board
RS485_RX: U10.4 (DI); also elsewhere on the board
RS485_TX: U10.1 (RO); also elsewhere on the board

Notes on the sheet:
RS485

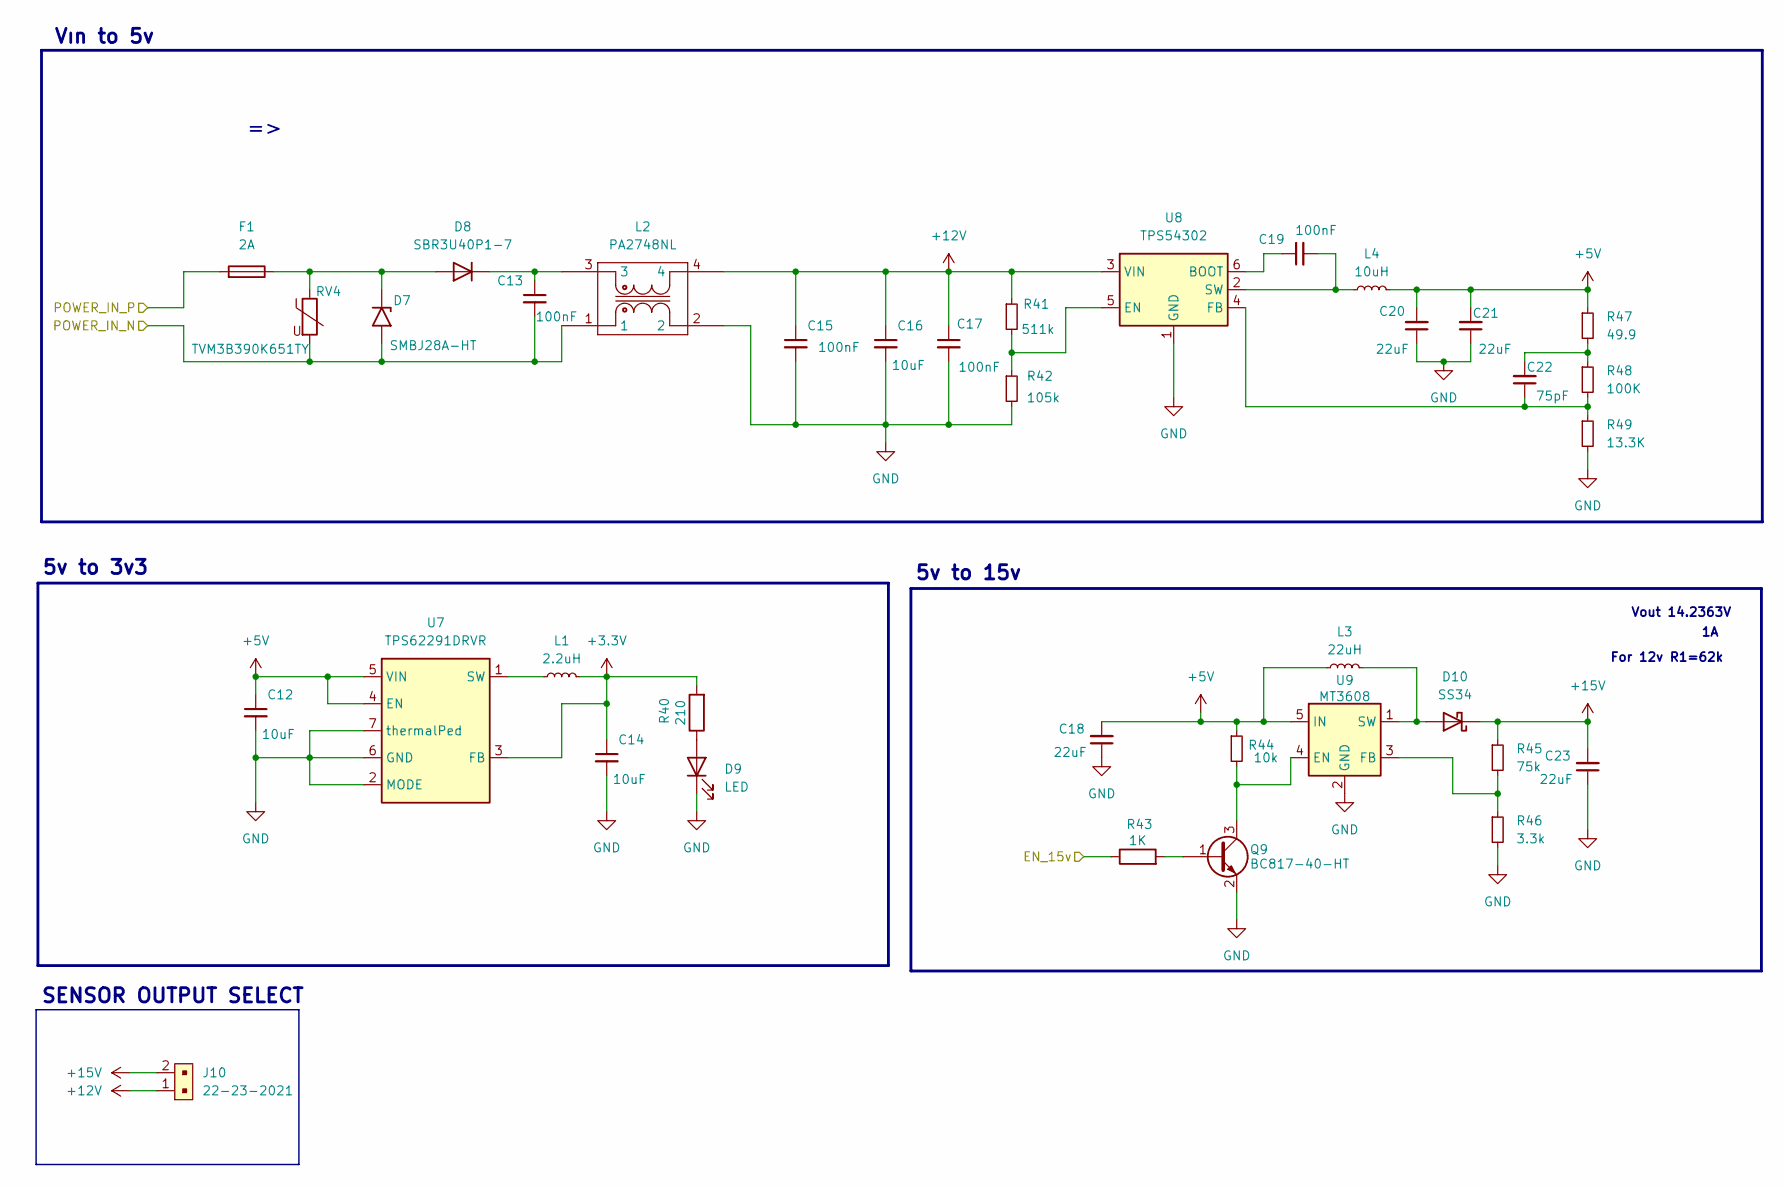
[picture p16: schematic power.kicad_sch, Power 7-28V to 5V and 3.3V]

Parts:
C12: 10uF; C_0603_1608Metric
C13, C15, C17, C19: 100nF; C_0603_1608Metric_Pad1.08x0.95mm_HandSolder
C14: 10uF; C_0603_1608Metric_Pad1.08x0.95mm_HandSolder
C16: 10uF; LED_0805_2012Metric_Pad1.15x1.40mm_HandSolder
C18, C23: 22uF; C_1206_3216Metric_Pad1.33x1.80mm_HandSolder
C20, C21: 22uF; C_0603_1608Metric_Pad1.08x0.95mm_HandSolder
C22: 75pF; C_0603_1608Metric_Pad1.08x0.95mm_HandSolder
D7: SMBJ28A-HT; D_SMB_Handsoldering
D8: SBR3U40P1-7; D_PowerDI-123
D9: LED; LED_0603_1608Metric_Pad1.05x0.95mm_HandSolder
D10: SS34; DO-214AB
F1: 2A; Fuse_0603_1608Metric_Pad1.05x0.95mm_HandSolder
J10: 22-23-2021; PinHeader_1x2_P2.54mm_Drill1.02mm; MPN 22-23-2021; Digi-Key_PN WM4200-ND
L1: 2.2uH; L_Murata_DFE201610P
L2: PA2748NL; pa2748
L3: 22uH; L_12x12mm_H6mm
L4: 10uH; INDC6060X300
Q9: BC817-40-HT; SOT-23
R40: 210; R_0603_1608Metric_Pad0.98x0.95mm_HandSolder
R41: 511k; R_0603_1608Metric_Pad0.98x0.95mm_HandSolder
R42: 105k; R_0603_1608Metric_Pad0.98x0.95mm_HandSolder
R43: 1K; R_0603_1608Metric_Pad0.98x0.95mm_HandSolder; DigiKey 311-210HRTR-ND
R44: 10k; R_0603_1608Metric_Pad0.98x0.95mm_HandSolder
R45: 75k; R_0603_1608Metric_Pad0.98x0.95mm_HandSolder
R46: 3.3k; R_0603_1608Metric_Pad0.98x0.95mm_HandSolder
R47: 49.9; R_0603_1608Metric_Pad0.98x0.95mm_HandSolder
R48: 100K; R_0603_1608Metric_Pad0.98x0.95mm_HandSolder
R49: 13.3K; R_0603_1608Metric_Pad0.98x0.95mm_HandSolder; DIGIKEY 0603SAF1332T5E
RV4: TVM3B390K651TY; R_1206_3216Metric_Pad1.30x1.75mm_HandSolder
U7: TPS62291DRVR; WSON6 (2x2)
U8: TPS54302; SOT-23-6
U9: MT3608; SOT-23-6

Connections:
+3.3V: C14.1, L1.2, R40.2, U7.3 (FB); also elsewhere on the board
+5V: C12.1, C18.2, C20.2, C21.2, L3.1, L4.2, R44.1, R47.1, U7.4 (EN), U7.5 (VIN), U9.5 (IN); also elsewhere on the board
+12V: C15.1, C16.1, C17.1, J10.1, L2.4, R41.1, U8.3 (VIN); also elsewhere on the board
+15V: C23.2, D10.K, J10.2, R45.1; also elsewhere on the board
/POWER/POWER_IN_N: C13.2, D7.2 (A2), L2.1, RV4.2; also elsewhere on the board
/POWER/POWER_IN_P: F1.2; also elsewhere on the board
EN_15V: R43.1; also elsewhere on the board
GND: C12.2, C14.2, C15.2, C16.2, C17.2, C18.1, C20.1, C21.1, C23.1, D9.1 (K), L2.2, Q9.2 (E), R42.2, R46.2, R49.2, U7.2 (MODE), U7.6 (GND), U7.7 (thermalPed), U8.1 (GND), U9.2 (GND); also elsewhere on the board
unnamed: C22.2, R47.2, R48.1
unnamed: D7.1 (A1), D8.2 (A), F1.1, RV4.1
unnamed: C13.1, D8.1 (K), L2.3
unnamed: D9.2 (A), R40.1
unnamed: Q9.1 (B), R43.2
unnamed: Q9.3 (C), R44.2, U9.4 (EN)
unnamed: L1.1, U7.1 (SW)
unnamed: C19.1, U8.6 (BOOT)
unnamed: R41.2, R42.1, U8.5 (EN)
unnamed: C22.1, R48.2, R49.1, U8.4 (FB)
unnamed: C19.2, L4.1, U8.2 (SW)
unnamed: R45.2, R46.1, U9.3 (FB)
unnamed: D10.A, L3.2, U9.1 (SW)

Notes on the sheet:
Vın to 5v
For 12v R1=62k
5v to 3v3
5v to 15v
Vout 14.2363V
SENSOR OUTPUT SELECT

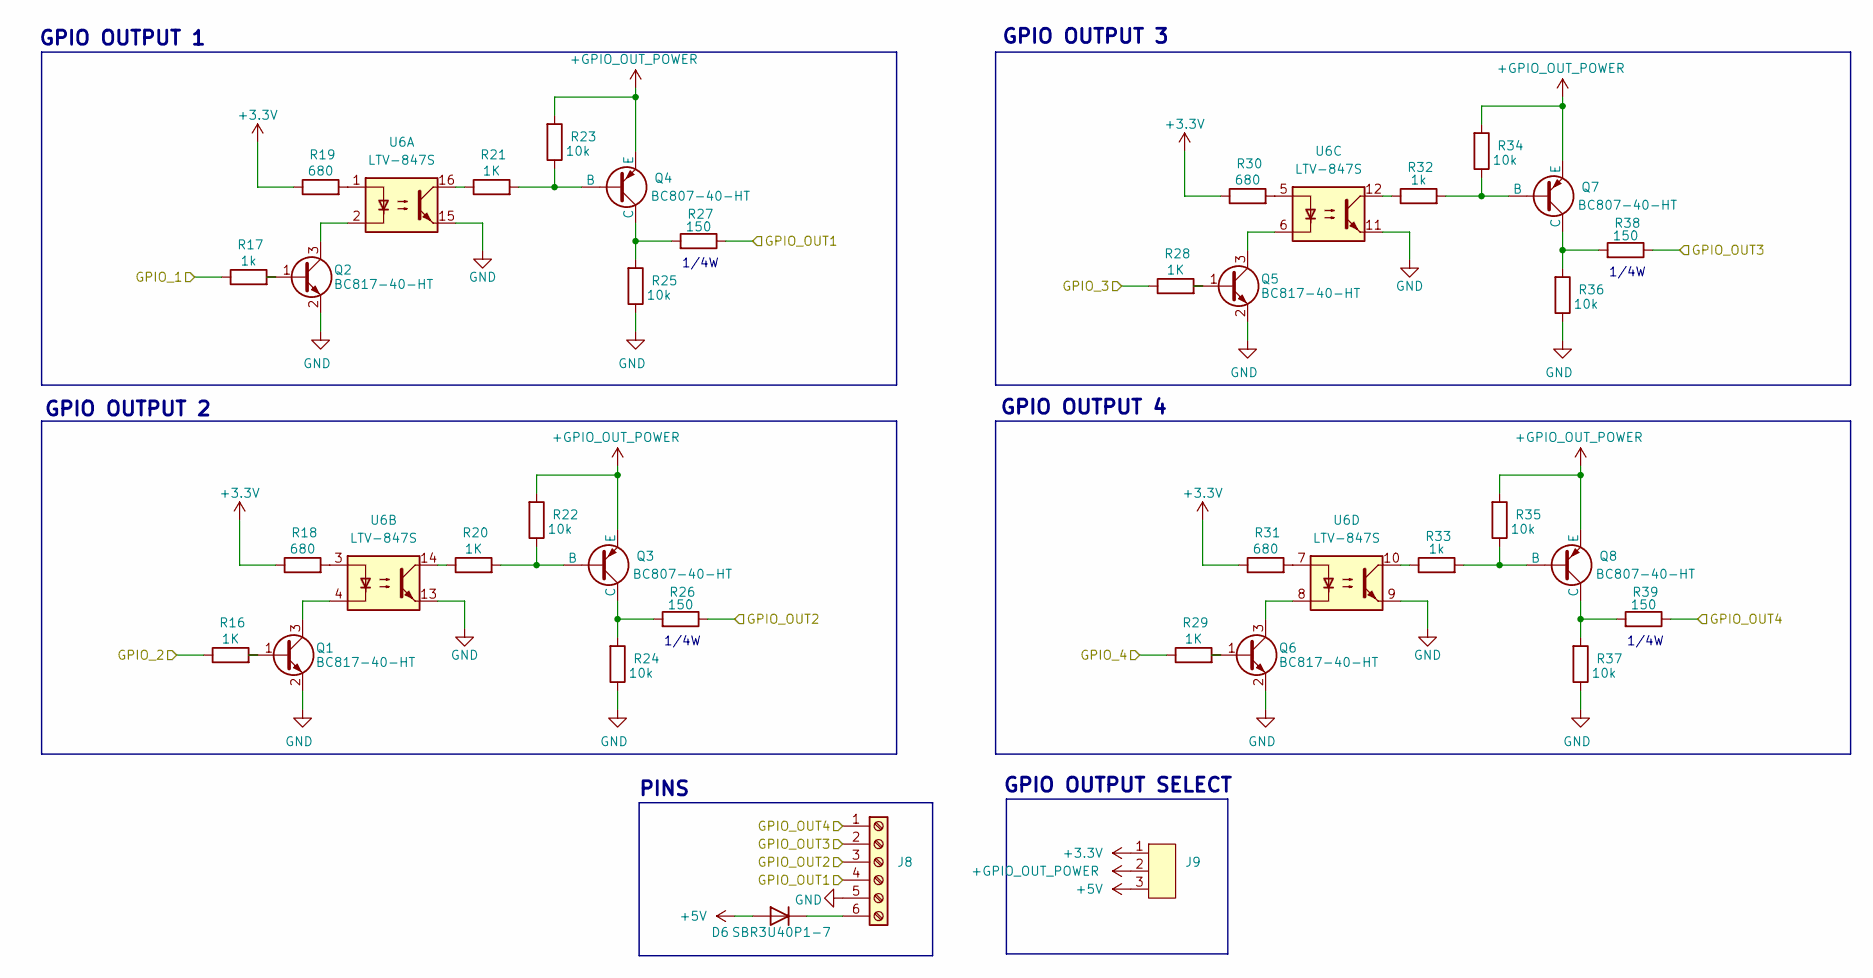
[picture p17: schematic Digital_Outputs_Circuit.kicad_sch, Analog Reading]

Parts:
D6: SBR3U40P1-7; D_PowerDI-123
J8: Hirose_DF13-06P-1.25DSA_1x06_P1.25mm_Vertical
J9: PinHeader_1x03_P2.54mm_Vertical
Q1, Q2, Q5, Q6: BC817-40-HT; SOT-23
Q3, Q4, Q7, Q8: BC807-40-HT; SOT-23-3
R16, R20, R21: 1K; R_0603_1608Metric_Pad0.98x0.95mm_HandSolder; DigiKey CRT03F7E1001
R17: 1k; R_0603_1608Metric_Pad0.98x0.95mm_HandSolder
R18, R19, R30, R31: 680; R_0603_1608Metric_Pad0.98x0.95mm_HandSolder; DigiKey 311-210HRTR-ND
R22, R23, R24, R25, R34, R35, R36, R37: 10k; R_0603_1608Metric_Pad0.98x0.95mm_HandSolder; DigiKey 311-210HRTR-ND
R26, R27, R38, R39: 150; R_1206_3216Metric_Pad1.30x1.75mm_HandSolder; DigiKey 311-210HRTR-ND
R28, R29: 1K; R_0603_1608Metric_Pad0.98x0.95mm_HandSolder; DigiKey 311-210HRTR-ND
R32, R33: 1k; R_0603_1608Metric_Pad0.98x0.95mm_HandSolder; DigiKey 311-210HRTR-ND
U6: LTV-847S; SMDIP-16_W9.53mm

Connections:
+3.3V: J9.1, R18.1, R19.1, R30.1, R31.1; also elsewhere on the board
+5V: D6.2 (A), J9.3; also elsewhere on the board
+GPIO_OUT_POWER: J9.2, Q3.2 (E), Q4.2 (E), Q7.2 (E), Q8.2 (E), R22.2, R23.2, R34.2, R35.2
/DIGITAL OUTPUTS/GPIO_OUT1: J8.4, R27.1
/DIGITAL OUTPUTS/GPIO_OUT2: J8.3, R26.1
/DIGITAL OUTPUTS/GPIO_OUT3: J8.2, R38.1
/DIGITAL OUTPUTS/GPIO_OUT4: J8.1, R39.1
GND: J8.5, Q1.2 (E), Q2.2 (E), Q5.2 (E), Q6.2 (E), R24.1, R25.1, R36.1, R37.1, U6.9, U6.11, U6.13, U6.15; also elsewhere on the board
GPIO_1: R17.1; also elsewhere on the board
GPIO_2: R16.1; also elsewhere on the board
GPIO_3: R28.1; also elsewhere on the board
GPIO_4: R29.1; also elsewhere on the board
unnamed: D6.1 (K), J8.6
unnamed: Q1.1 (B), R16.2
unnamed: Q1.3 (C), U6.4
unnamed: Q2.1 (B), R17.2
unnamed: Q2.3 (C), U6.2
unnamed: Q3.1 (B), R20.2, R22.1
unnamed: Q3.3 (C), R24.2, R26.2
unnamed: Q4.1 (B), R21.2, R23.1
unnamed: Q4.3 (C), R25.2, R27.2
unnamed: Q5.1 (B), R28.2
unnamed: Q5.3 (C), U6.6
unnamed: Q6.1 (B), R29.2
unnamed: Q6.3 (C), U6.8
unnamed: Q7.1 (B), R32.2, R34.1
unnamed: Q7.3 (C), R36.2, R38.2
unnamed: Q8.1 (B), R33.2, R35.1
unnamed: Q8.3 (C), R37.2, R39.2
unnamed: R18.2, U6.3
unnamed: R19.2, U6.1
unnamed: R20.1, U6.14
unnamed: R21.1, U6.16
unnamed: R30.2, U6.5
unnamed: R31.2, U6.7
unnamed: R32.1, U6.12
unnamed: R33.1, U6.10

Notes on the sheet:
GPIO OUTPUT 1
PINS
GPIO OUTPUT 2
1/4W
GPIO OUTPUT SELECT
GPIO OUTPUT 4
GPIO OUTPUT 3

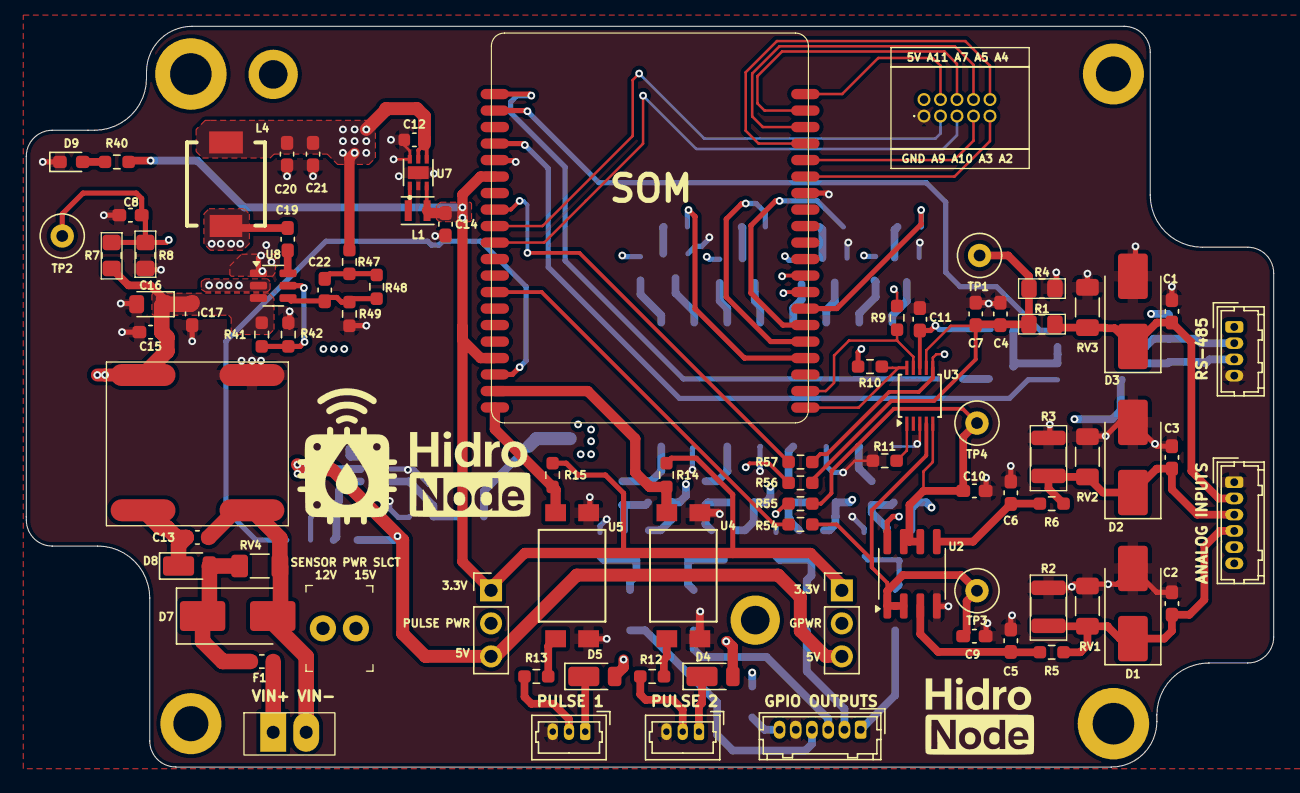
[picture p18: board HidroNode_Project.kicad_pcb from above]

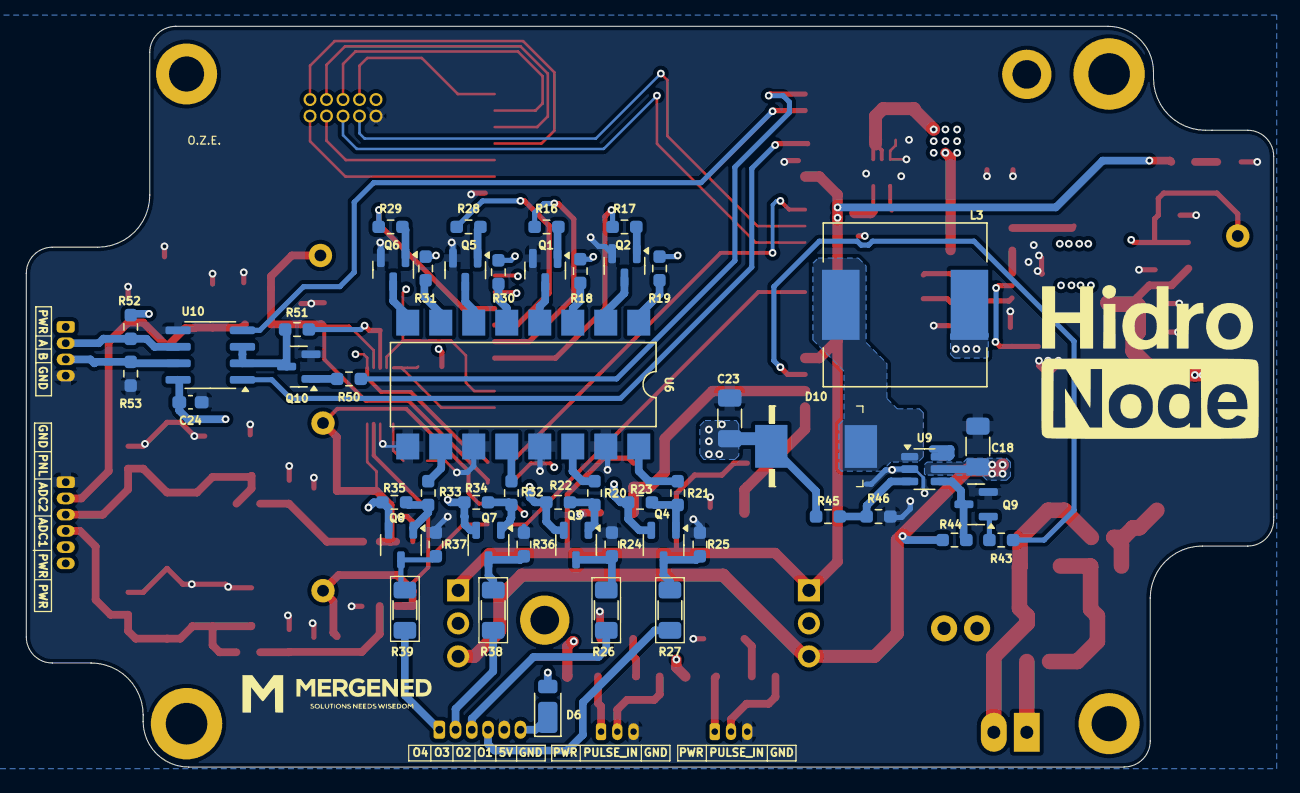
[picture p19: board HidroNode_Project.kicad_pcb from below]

Board: 4 copper layers, 96.0 x 57.0 mm, 138 parts (51 on the bottom side), 95 nets.
